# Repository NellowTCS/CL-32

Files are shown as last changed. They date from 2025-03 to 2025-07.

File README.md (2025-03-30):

Here is a little peek at the bones of CL-32

The case files are an older version, but they are nice to look at

Please be gentle with the code, its a bit of a mess, but that will soon change ;)

The whole thing will be open source at some point in the future, but I will just give you the basics for now

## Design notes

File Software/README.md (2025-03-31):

Some brief info for you to make code with :)

The keyboard uses an TCA8418 IC to save i/o pins. This stores the key events in a buffer so that they can be read as needed
https://www.ti.com/lit/gpn/TCA8418

The RTC is a RV-3032-C7 which allows the date/time to be stored for a better user experience
https://www.microcrystal.com/fileadmin/Media/Products/RTC/App.Manual/RV-3032-C7_App-Manual.pdf

The screen is GDEY029T71H from GoodDisplay. It is a higher resolution 2.9" screen and still has the fast refresh
https://www.good-display.com/product/540.html

The add-on cards will have an EEPROM chip on them, to allow the storage of some information about the card, and some sample code for using it. This is still a work in progress, but will probably be M24M02-DRMN6TP
https://www.st.com/resource/en/datasheet/m24m02-dr.pdf

There will be 2 i2c ports (stemma/qwiic), the USB port, then the m.2 add-on slot

I2c 1 is on the same pins as the internal stuff for the keyboard and RTC (SDA:pin 1 - SCL:pin 2 - INT:pin 3)
I2c 2 share some of the data pins from the m.2 slot (SDA: pin 47 - SCL:pin 48)
The USB is connected directly to the ESP
The m.2 slot has basically everything connected. USB/UART/i2c/pins 8,15,16,17,18,21,35,36,37,38,39,40,41,42,47,48 (although pins 35,36,37 are tied to the PSRAM so may be useless!!)

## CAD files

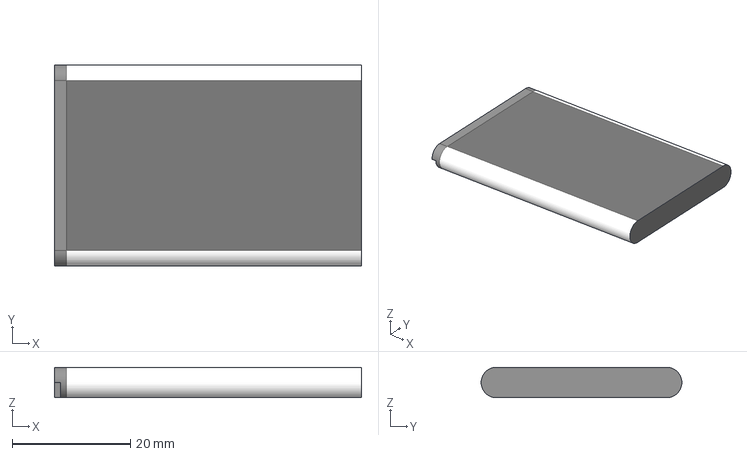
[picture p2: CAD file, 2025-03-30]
Case/BATTERIE_Model BL-5C.step
52.0 x 34.0 x 5.15 mm

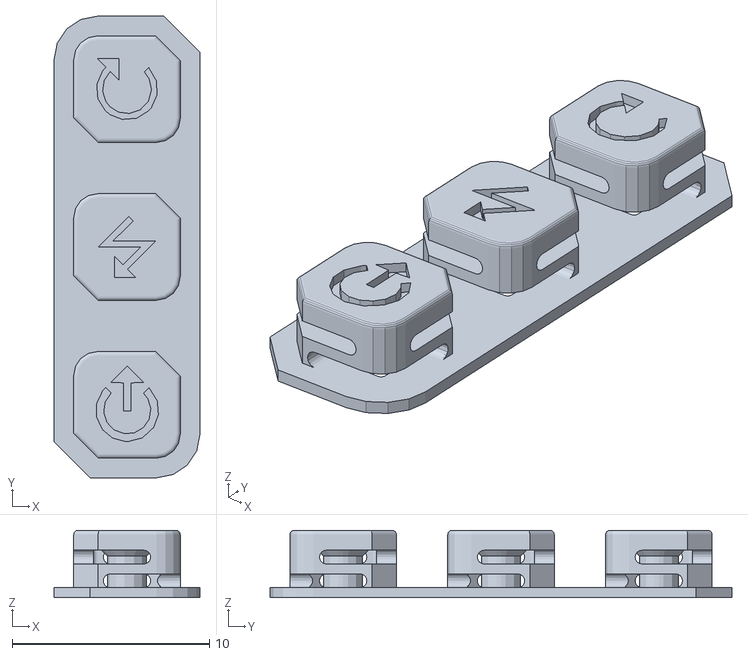
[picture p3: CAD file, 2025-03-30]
Case/v0.2/CL-32-pow.stl
7.40 x 23.4 x 3.40

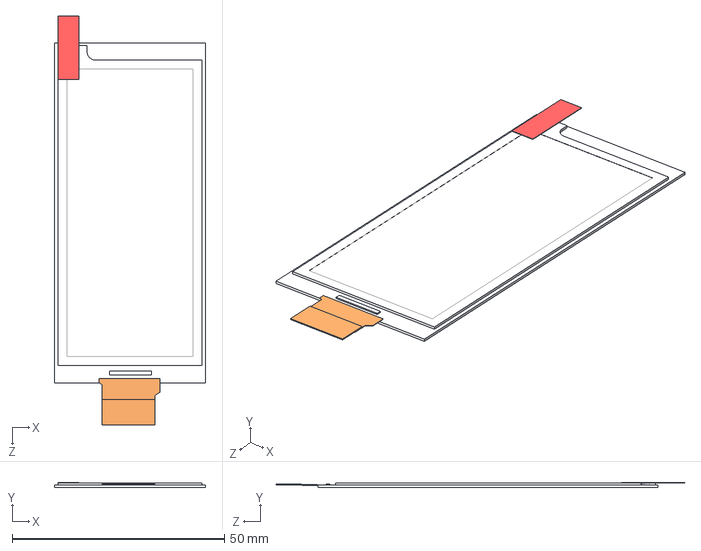
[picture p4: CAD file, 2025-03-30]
Case/GDEY029T71H-3D.STEP
35.6 x 1.10 x 96.3 mm

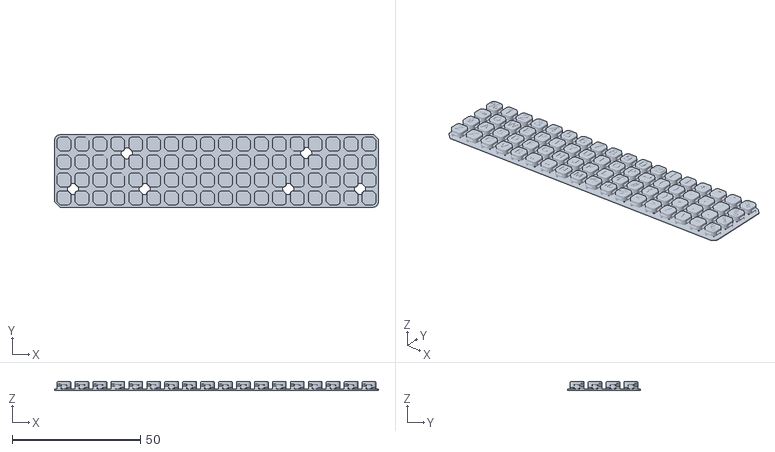
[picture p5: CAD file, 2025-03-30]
Case/v0.2/CL-32-but.stl
126.4 x 28.4 x 3.40

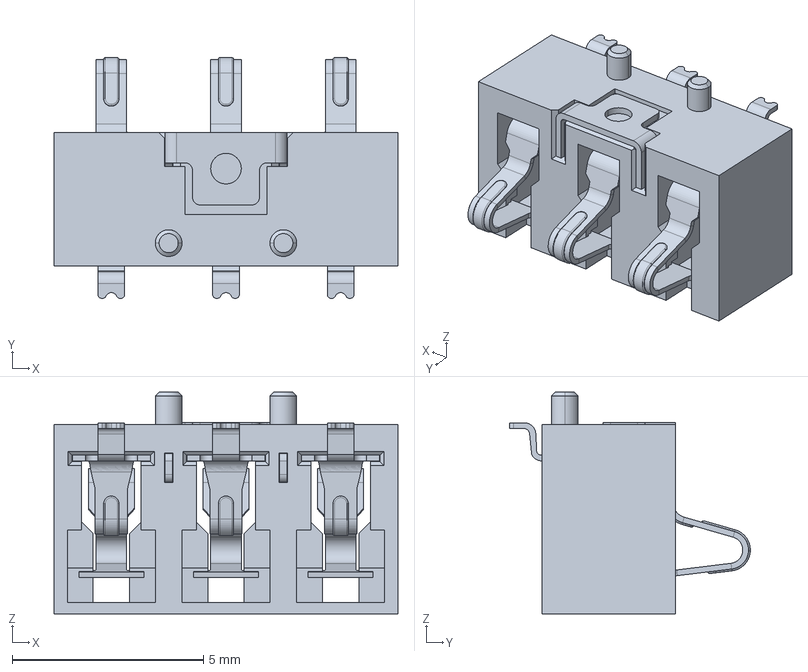
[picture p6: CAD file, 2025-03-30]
Case/BC-29-3PD500_1749528430.214.step
9.00 x 6.30 x 5.80 mm
eMachineShop.1.1
eMachineShop.1.2
eMachineShop.1.3
eMachineShop.1.4
eMachineShop.1.5
eMachineShop.1.6
eMachineShop.1.7
eMachineShop.1.8
eMachineShop.1.9
eMachineShop.1.10
eMachineShop.1.11
eMachineShop.1.12
eMachineShop.1.13
eMachineShop.1.14
eMachineShop.1.15
eMachineShop.1.16
eMachineShop.1.17
eMachineShop.1.18
eMachineShop.1.19
eMachineShop.1.20
eMachineShop.1.21
eMachineShop.1.22
eMachineShop.1.23
eMachineShop.1.24
eMachineShop.1.25
eMachineShop.1.26
eMachineShop.1.27
eMachineShop.1.28
eMachineShop.1.29
eMachineShop.1.30
eMachineShop.1.31
eMachineShop.1.32
eMachineShop.1.33
eMachineShop.1.34
eMachineShop.1.35
eMachineShop.1.36
eMachineShop.1.37
eMachineShop.1.38
eMachineShop.1.39
eMachineShop.1.40
eMachineShop.1.41
eMachineShop.1.42
eMachineShop.1.43
eMachineShop.1.44
eMachineShop.1.45
eMachineShop.1.46
eMachineShop.1.47
eMachineShop.1.48
eMachineShop.1.49
eMachineShop.1.50
eMachineShop.1.51
eMachineShop.1.52
eMachineShop.1.53
eMachineShop.1.54
eMachineShop.1.55
eMachineShop.1.56
eMachineShop.1.57
eMachineShop.1.58
eMachineShop.1.59
eMachineShop.1.60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

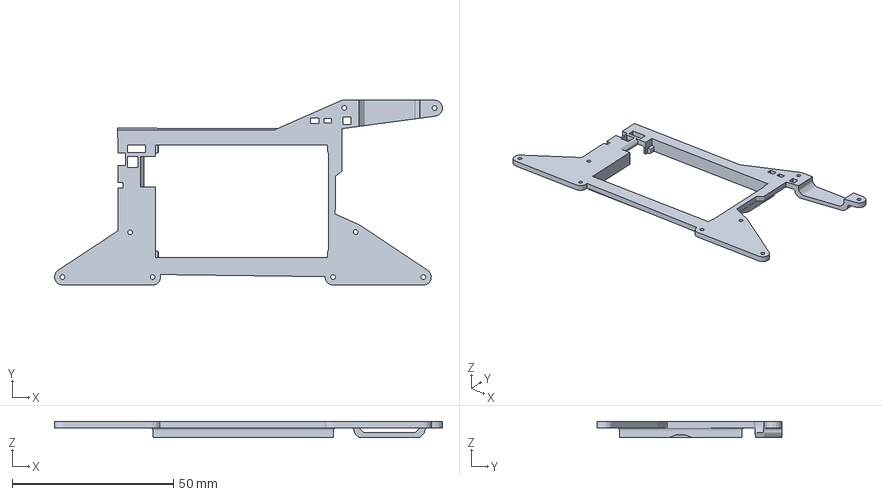
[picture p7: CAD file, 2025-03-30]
Case/v0.2/CL-32-bat.3mf
120.4 x 57.5 x 5.00 mm

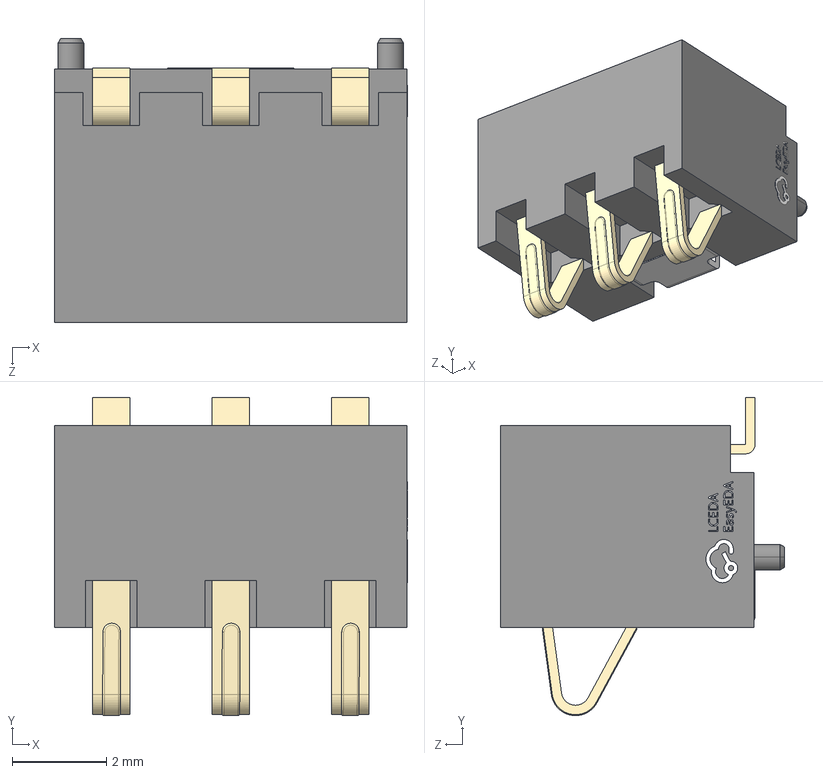
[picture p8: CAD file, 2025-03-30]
Case/BAT-SMD_GT-BTP25003-0540A-002A.step
7.51 x 6.77 x 6.05 mm

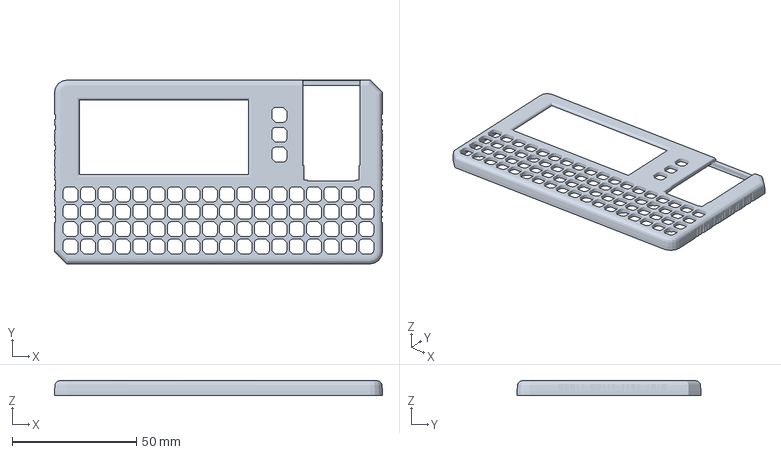
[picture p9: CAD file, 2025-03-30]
Case/v0.2/CL-32-front.3mf
132.0 x 74.0 x 5.90 mm

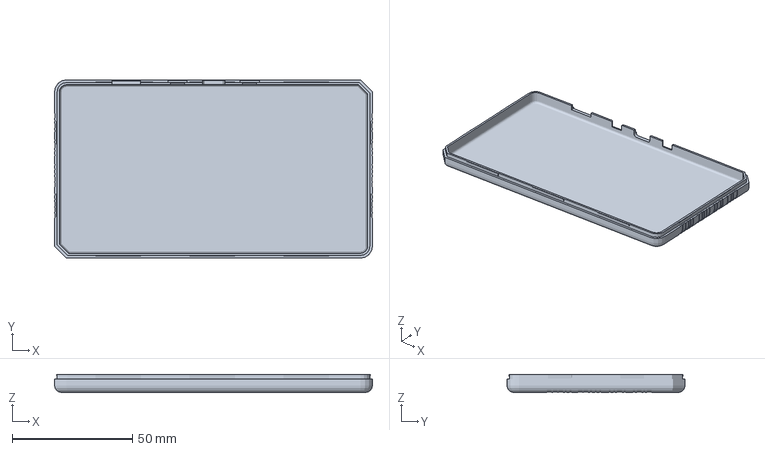
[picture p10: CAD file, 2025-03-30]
Case/v0.2/CL-32-back.3mf
132.0 x 74.0 x 7.50 mm

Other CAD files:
Case/v0.2/CL-32-bat.stl

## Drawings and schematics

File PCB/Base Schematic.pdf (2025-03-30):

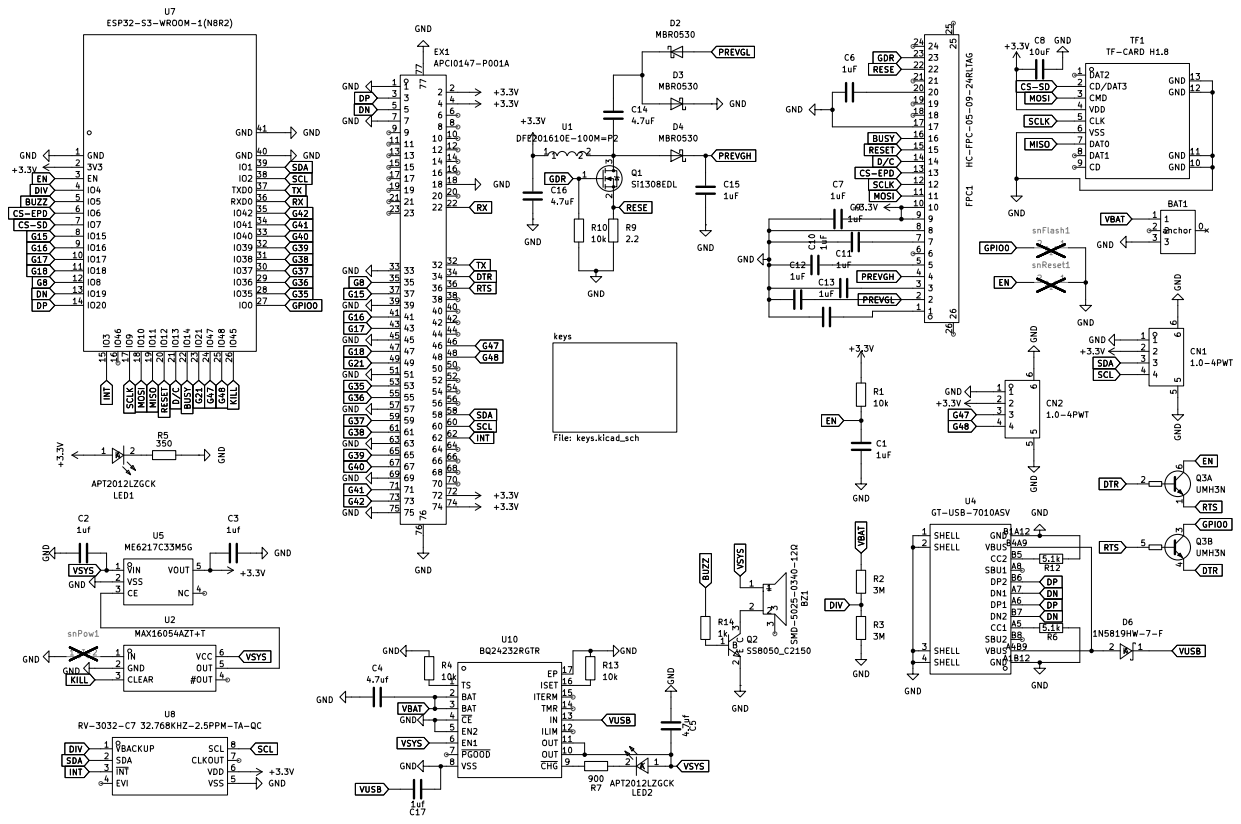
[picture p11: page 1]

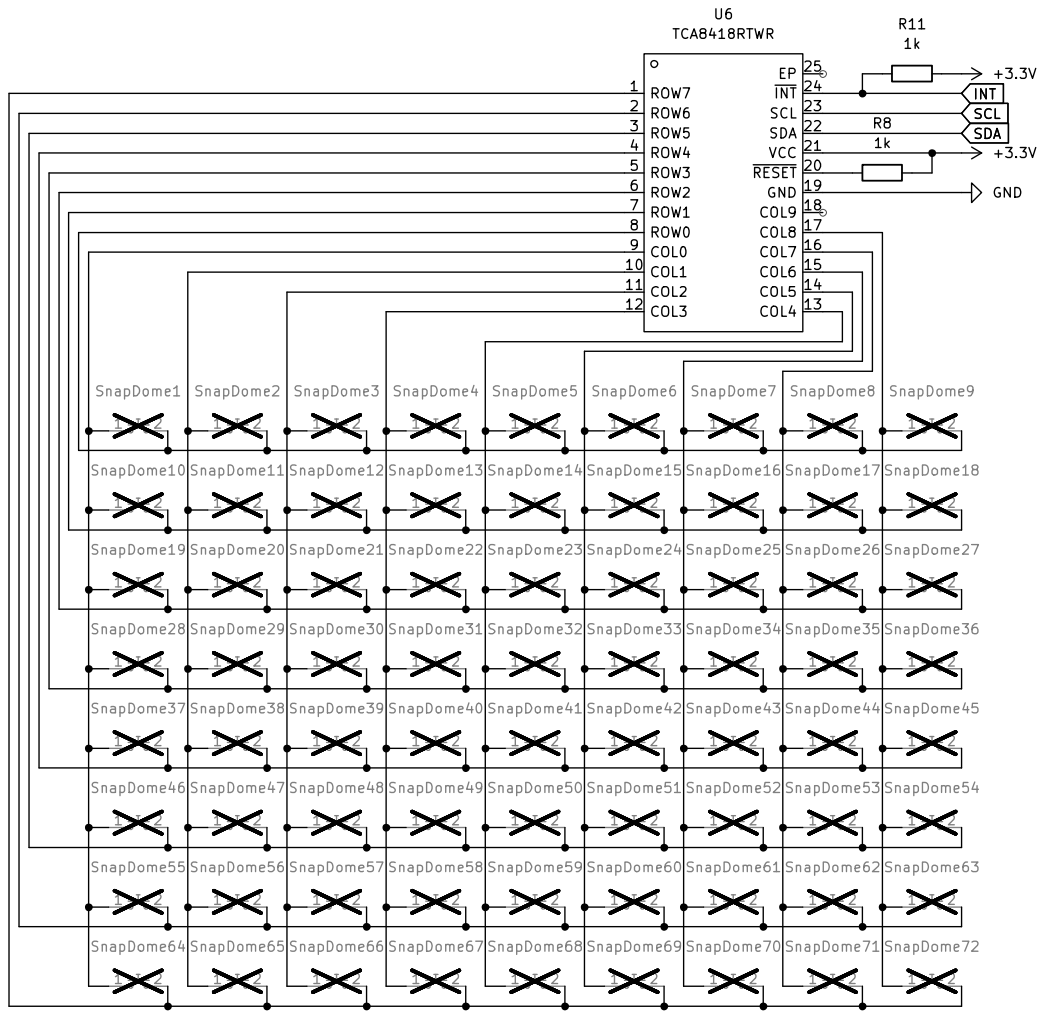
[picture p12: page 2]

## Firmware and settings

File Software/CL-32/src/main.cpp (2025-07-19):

#include "config.h"
#include "display_manager.h"
#include "file_manager.h"
#include "keyboard_manager.h"
#include "rtc_manager.h"
#include <Wire.h>
#include <SD.h>
#include <CL_32_logo.h>
#include <CL32_logo.h>
#include "bitmaps/Bitmaps168x384.h"

void setup() {
    Wire.begin(CL32_sda, CL32_scl);
    Serial.begin(115200);
    Serial.println("Starting setup...");
    
    // Initialize chip select pins
    pinMode(CL32_sd_cs, OUTPUT);
    pinMode(CL32_epd_cs, OUTPUT);
    digitalWrite(CL32_sd_cs, HIGH); // Deselect SD card
    digitalWrite(CL32_epd_cs, HIGH); // Deselect e-paper display
    Serial.println("CS pins initialized: SD HIGH, EPD HIGH");
    
    // Initialize SPI with proper pin assignments
    hspi.begin(CL32_sck, CL32_miso, CL32_mosi, -1); // Don't assign CS here
    
    // Initialize display first
    display.epd2.selectSPI(hspi, SPISettings(4000000, MSBFIRST, SPI_MODE0));
    digitalWrite(CL32_epd_cs, LOW); // Select display for initialization
    display.init(115200);
    display.setRotation(3);
    display.setFullWindow();
    display.fillScreen(GxEPD_WHITE);
    display.drawBitmap((display.width() / 2) - 148, (display.height() / 2) - 64, image_data_cl32_logo, 296, 128, GxEPD_WHITE, GxEPD_BLACK);
    display.display(true);
    display.hibernate();
    digitalWrite(CL32_epd_cs, HIGH); // Ensure display is deselected after use
    Serial.println("Display initialized and hibernated");
    
    // Small delay to ensure display operations complete
    delay(100);
    
    // Initialize SD card with proper chip select handling
    bool sdInitialized = false;
    for (int i = 0; i < 3 && !sdInitialized; i++) {
        Serial.print("Attempting SD card initialization, attempt ");
        Serial.println(i + 1);
        
        digitalWrite(CL32_epd_cs, HIGH); // Ensure display is deselected
        digitalWrite(CL32_sd_cs, LOW);   // Select SD card
        Serial.println("SD CS LOW for initialization");
        
        if (SD.begin(CL32_sd_cs, hspi)) {
            // Test SD card access
            File test = SD.open("/");
            if (test) {
                test.close();
                sdInitialized = true;
                Serial.println("SD card initialized and tested successfully");
            } else {
                Serial.println("SD card mount test failed");
            }
        } else {
            Serial.println("SD card initialization failed");
        }
        
        digitalWrite(CL32_sd_cs, HIGH); // Deselect SD card
        Serial.println("SD CS HIGH after initialization attempt");
        
        if (!sdInitialized) {
            delay(500); // Wait before retrying
        }
    }
    
    if (!sdInitialized) {
        Serial.println("SD card initialization failed after 3 attempts!");
        sprintf(statusMsg, "SD Card Fail");
        statusMsgTime = millis();
    } else {
        // Initialize file system variables
        strcpy(filePath, "/"); // Use root directory, not /sd
        newFile(); // Initialize with a new file
    }
    
    // Initialize keyboard
    Wire.beginTransmission(KEYBOARD_ADDRESS);
    Wire.write(0x01);
    Wire.write(0x19);
    Wire.endTransmission();
    Wire.beginTransmission(KEYBOARD_ADDRESS);
    Wire.write(0x02);
    Wire.write(0xff);
    Wire.endTransmission();
    Wire.beginTransmission(KEYBOARD_ADDRESS);
    Wire.write(0x1d);
    Wire.write(0xff);
    Wire.endTransmission();
    Wire.beginTransmission(KEYBOARD_ADDRESS);
    Wire.write(0x1e);
    Wire.write(0xff);
    Wire.endTransmission();
    Wire.beginTransmission(KEYBOARD_ADDRESS);
    Wire.write(0x1f);
    Wire.write(0x01);
    Wire.endTransmission();
    Wire.beginTransmission(KEYBOARD_ADDRESS);
    Wire.write(0x29);
    Wire.write(0xff);
    Wire.endTransmission();
    Wire.beginTransmission(KEYBOARD_ADDRESS);
    Wire.write(0x2a);
    Wire.write(0xff);
    Wire.endTransmission();
    Wire.beginTransmission(KEYBOARD_ADDRESS);
    Wire.write(0x2b);
    Wire.write(0x01);
    Wire.endTransmission();
    
    pinMode(CL32_int, INPUT);
    pinMode(CL32_buz, OUTPUT);
    
    // Initialize RTC
    Wire.beginTransmission(RTC_ADDRESS);
    Wire.write(0xc0);
    Wire.write(0x20);
    Wire.endTransmission();
    
    // Initialize variables
    iLoop = 0;
    iVolt = 0;
    analogReadResolution(12);
    iBatVolt = (analogRead(CL32_div) / 500.0) * 5.3; // Fix integer division
    
    delay(1000);
    iMode = EDIT;
    bMenu = true;
    drawScreen(true);
    Serial.println("Setup complete");
}

void loop() {
    iVolt += analogRead(CL32_div);
    iLoop++;
    if (iLoop % 500 == 1) {
        iBatVolt = (iVolt / 500.0) * 5.3; // Fix integer division
        iVolt = 0;
    }
    if (!digitalRead(CL32_int)) {
        readKeys();
    }
    delay(100);
}

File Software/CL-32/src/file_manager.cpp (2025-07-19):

#include "file_manager.h"
#include "editor.h"
#include <SD.h>

// Define maximum limits if not defined elsewhere
#ifndef MAX_FILES
#define MAX_FILES 100  // Adjust this value based on your memory constraints
#endif

#ifndef MAX_FOLDERS
#define MAX_FOLDERS 50  // Adjust this value based on your memory constraints
#endif

// Helper function to reinitialize SD card if needed
bool ensureSDReady() {
    static unsigned long lastSDCheck = 0;
    static bool sdWasWorking = false;
    static int retryCount = 0;
    
    // Always try to reinitialize if SD wasn't working, or every 5 seconds if it was
    if (!sdWasWorking || (millis() - lastSDCheck > 5000)) {
        lastSDCheck = millis();
        
        Serial.println("Checking SD card accessibility...");
        
        // End any existing SD session first
        SD.end();
        delay(200); // Give more time for cleanup
        
        // Toggle CS pin to reset state
        digitalWrite(CL32_sd_cs, HIGH);
        delay(50);
        digitalWrite(CL32_sd_cs, LOW);
        delay(50);
        digitalWrite(CL32_sd_cs, HIGH);
        delay(100);
        
        // Try different SPI speeds in order of preference
        uint32_t speeds[] = {4000000, 1000000, 400000}; // 4MHz, 1MHz, 400kHz
        bool initialized = false;
        
        for (int i = 0; i < 3 && !initialized; i++) {
            Serial.print("Attempting SD init at ");
            Serial.print(speeds[i]);
            Serial.println(" Hz");
            
            initialized = SD.begin(CL32_sd_cs, SPI, speeds[i]);
            if (!initialized) {
                delay(500);
            }
        }
        
        if (initialized) {
            // Double-check by trying to access root directory
            if (SD.exists("/")) {
                Serial.println("SD card initialized and accessible");
                sdWasWorking = true;
                retryCount = 0;
                return true;
            } else {
                Serial.println("SD initialized but root directory not accessible");
                initialized = false;
            }
        }
        
        if (!initialized) {
            retryCount++;
            Serial.print("SD card initialization failed (attempt ");
            Serial.print(retryCount);
            Serial.println(")");
            sdWasWorking = false;
            return false;
        }
    }
    
    return sdWasWorking;
}

// Hardware diagnostic function - call this in setup() or when SD fails
void diagnoseSD() {
    Serial.println("=== SD Card Diagnostic ===");
    Serial.print("CS Pin: ");
    Serial.println(CL32_sd_cs);
    Serial.print("EPD CS Pin: ");
    Serial.println(CL32_epd_cs);
    
    // Check pin states
    Serial.print("SD CS state: ");
    Serial.println(digitalRead(CL32_sd_cs) ? "HIGH" : "LOW");
    Serial.print("EPD CS state: ");
    Serial.println(digitalRead(CL32_epd_cs) ? "HIGH" : "LOW");
    
    // Test different initialization approaches
    Serial.println("Testing SD initialization approaches...");
    
    // Approach 1: Default settings
    SD.end();
    delay(500);
    digitalWrite(CL32_epd_cs, HIGH);
    digitalWrite(CL32_sd_cs, HIGH);
    delay(100);
    
    if (SD.begin(CL32_sd_cs)) {
        Serial.println("✓ Default init successful");
    } else {
        Serial.println("✗ Default init failed");
        
        // Approach 2: With explicit SPI and lower speed
        SD.end();
        delay(500);
        if (SD.begin(CL32_sd_cs, SPI, 400000)) {
            Serial.println("✓ Low-speed init successful");
        } else {
            Serial.println("✗ Low-speed init failed");
        }
    }
    
    Serial.println("=== End Diagnostic ===");
}

void saveFile() {
    File curFile;
    char fullFileName[200];
    
    // Build full path properly
    if (strlen(filePath) > 1) {
        snprintf(fullFileName, sizeof(fullFileName), "%s/%s", filePath, fileName);
    } else {
        snprintf(fullFileName, sizeof(fullFileName), "/%s", fileName);
    }
    
    Serial.print("Saving file: ");
    Serial.println(fullFileName);
    
    // Ensure e-paper display is deselected and SD is selected
    digitalWrite(CL32_epd_cs, HIGH);
    delay(20); // Increased delay for signal stability
    digitalWrite(CL32_sd_cs, LOW);
    delay(10);
    Serial.println("SD CS LOW, EPD CS HIGH for saveFile");
    
    // Try multiple times to get SD working
    bool sdReady = false;
    for (int attempt = 0; attempt < 3; attempt++) {
        if (ensureSDReady()) {
            sdReady = true;
            break;
        }
        Serial.print("SD retry attempt ");
        Serial.println(attempt + 1);
        delay(1000); // Wait between attempts
    }
    
    if (!sdReady) {
        Serial.println("SD card not accessible after multiple attempts");
        sprintf(statusMsg, "SD Not Ready");
        statusMsgTime = millis();
        digitalWrite(CL32_sd_cs, HIGH);
        
        // Run diagnostic if SD keeps failing
        diagnoseSD();
        return;
    }
    
    // Remove existing file and create new one to ensure clean write
    if (SD.exists(fullFileName)) {
        if (!SD.remove(fullFileName)) {
            Serial.println("Warning: Could not remove existing file");
        }
    }
    
    curFile = SD.open(fullFileName, FILE_WRITE);
    if (curFile) {
        size_t written = curFile.write((uint8_t*)fileBuffer, fileSize);
        curFile.close();
        
        if (written == fileSize) {
            sprintf(statusMsg, "Saved: %s", fileName);
            Serial.print("File saved successfully, wrote ");
            Serial.print(written);
            Serial.println(" bytes");
        } else {
            sprintf(statusMsg, "Save Incomplete");
            Serial.print("Warning: Expected to write ");
            Serial.print(fileSize);
            Serial.print(" bytes, actually wrote ");
            Serial.println(written);
        }
    } else {
        Serial.println("Failed to open file for writing");
        Serial.println("Running SD diagnostic...");
        diagnoseSD();
        sprintf(statusMsg, "Save Failed");
    }
    statusMsgTime = millis();
    digitalWrite(CL32_sd_cs, HIGH);
    Serial.println("SD CS HIGH after saveFile");
}

void newFile() {
    memset(fileBuffer, 0, sizeof(fileBuffer));
    fileSize = 0;
    strcpy(fileName, "newfile.txt");
    strcpy(filePath, "/"); // Use root directory
    windowX = windowY = iRow = iCol = 0;
    getLines();
    sprintf(statusMsg, "New file started");
    statusMsgTime = millis();
    Serial.println("New file created");
}
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

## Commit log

2025-03-30 make it so
    [BAT-SMD_GT-BTP25003-0540A-002A.step, BATTERIE_Model BL-5C.step, BC-29-3PD500_1749528430.214.step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]
2025-03-30 added some pcb data
2025-07-19 sd card not working?
    [file_manager.cpp, main.cpp]
